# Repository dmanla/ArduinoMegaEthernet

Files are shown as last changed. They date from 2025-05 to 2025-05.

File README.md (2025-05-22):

# Arduino-Mega Compatible Secure Connectivity Development Platform

**WARNING**: This project is under development and has not yet been validated.

This is an open hardware platform designed for the development of secure wired-network applications. It is fully compatible with all Arduino Mega-compatible hardware and software.

This project was inspired by (but not a copy of) the Freetronics EtherMega: https://github.com/freetronics/EtherMega
This project was created as an alternative to the platform offered by Freetronics.

Features:
- CH340 USB->Serial Converter (Functionally similar to FT232, Driver should be installed automatically)
- Jumper Configurable IO: Certain pins (D3, D6, D8, D9, D13) can be connected to the headers or to integrated peripheral pins.
- 5V 2A USB-C Input
- 6V - 32V VIN Input 
- MicroSD Card Slot
- 10/100 Ethernet provided over SPI using the W5500
- SE050 EdgeLock Plug and Trust Secure Element to provide security features for connected applications, accessible using I2C
- ISM330DHCX Inertial Measurement Unit, accessible using I2C
- MCP7940N Real Time Clock, accessible using I2C
- Level Shifted I2C: Provides connection points for 3V3 I2C Devices (Extra Header), and 5V I2C Devices (Standard Mega Headers)

## Top Render
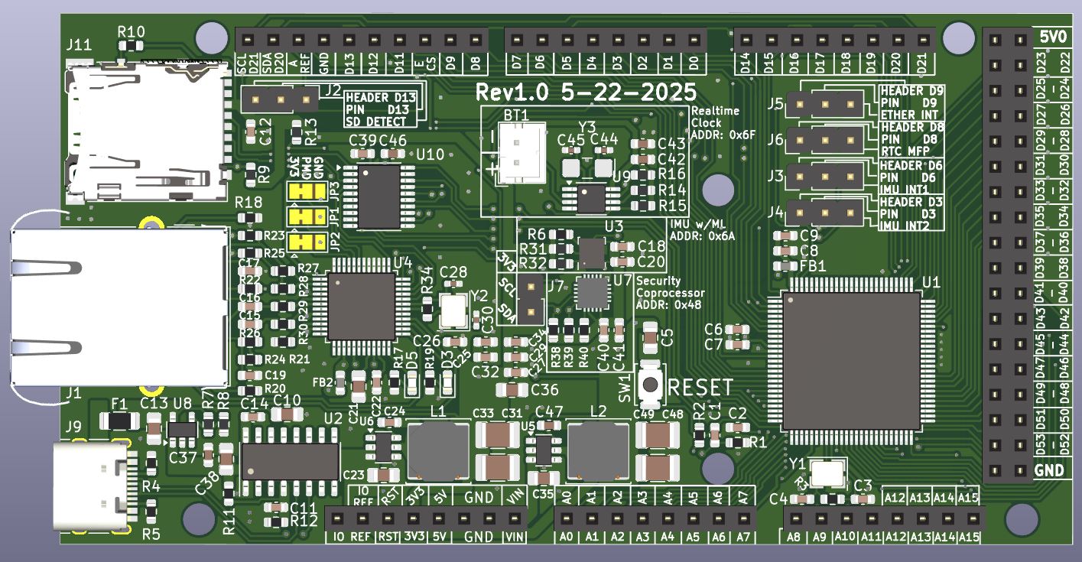
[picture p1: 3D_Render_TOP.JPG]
Render of Top of PCB


## Bottom Render
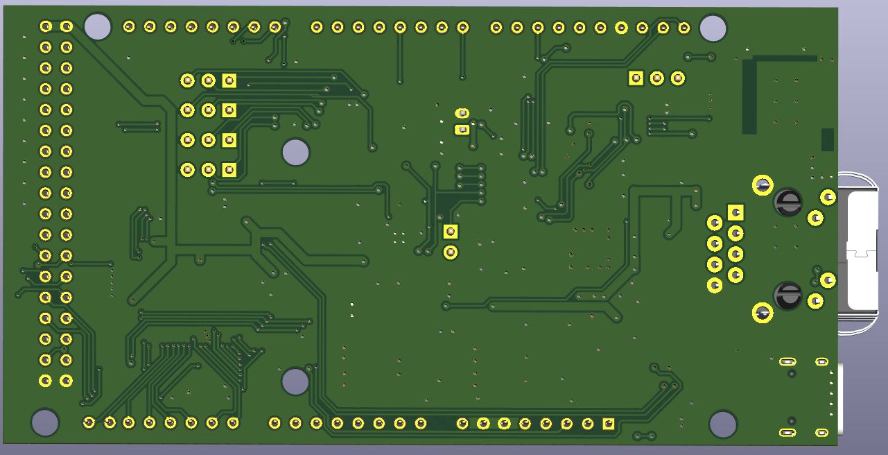
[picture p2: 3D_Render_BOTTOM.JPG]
Render of Bottom of PCB


## Side Render
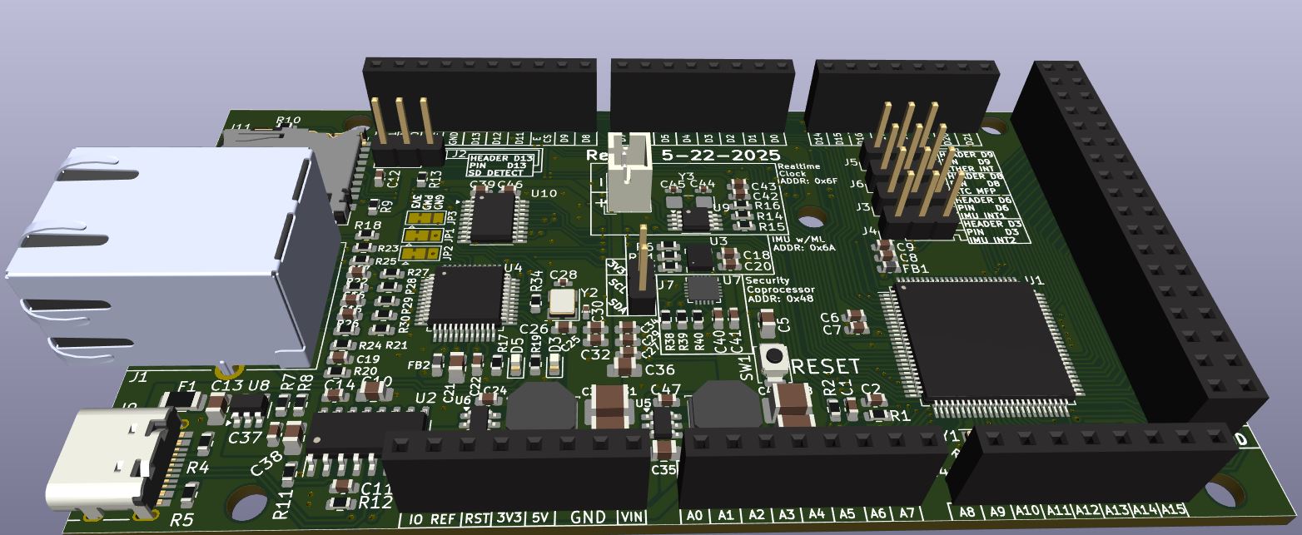
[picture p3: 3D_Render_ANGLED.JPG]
Render of Side of PCB


## Relevant Datasheets

- [CH340N](https://datasheet.lcsc.com/szlcsc/Jiangsu-Qin-Heng-CH340C_C84681.pdf): USB->Serial Bridge
- [AP22805AW5](https://www.diodes.com/assets/Datasheets/AP22804_14.pdf): USB Protection
- [AP63205](https://www.diodes.com/assets/Datasheets/AP63200-AP63201-AP63203-AP63205.pdf): DC-DC Switching Converters
- [W5500](http://wizwiki.net/wiki/lib/exe/fetch.php/products:w5500:w5500_ds_v109e.pdf): SPI->Ethernet Bridge
- [ISM330DHCX](https://www.st.com/resource/en/datasheet/ism330dhcx.pdf): "AI Enabled" Inertial Measurement Unit
- [SE050C2HQ1](https://www.nxp.com/docs/en/data-sheet/SE050-DATASHEET.pdf): Security Coprocessor
- [MCP7940N](http://ww1.microchip.com/downloads/en/DeviceDoc/20005010F.pdf): Real-Time Clock **with** Battery Backup
- [Atmega2560](http://ww1.microchip.com/downloads/en/DeviceDoc/Atmel-2549-8-bit-AVR-Microcontroller-ATmega640-1280-1281-2560-2561_datasheet.pdf): Main Microcontroller

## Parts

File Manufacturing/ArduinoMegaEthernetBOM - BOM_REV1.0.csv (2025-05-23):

 |  |  | Arduino Mega with Ethernet
Item # | Designator | *Qty | Manufacturer | Mfg Part # | Description / Value | Package/Footprint | Type | Your Instructions / Notes | Unit Cost | Per Board Cost
1 | BT1 | 1 | JST Sales America Inc. | B2B-PH-K-S | CONN HEADER VERT 2POS 2MM | JST_PH_B2B-PH-K_1x02_P2.00mm_Vertical | THT | N/A | $0.12 | $0.12
2 | C44, C45 | 2 | Murata Electronics | GRM0335C1H120JA01D | CAP CER 12PF 50V C0G/NP0 0603 | 0402 (1005 Metric) | SMD | N/A | $0.10 | $0.20
3 | C2, C3, C4 | 2 | Walsin Technology | 0603N220J500CT | CAP CER 22PF 50V C0G/NP0 0603 | C_0603_1608Metric | SMD | N/A | $0.10 | $0.20
4 | C5, C13, C23, C35, C36, C38 | 6 | Murata Electronics | GRM21BR61H106KE43L | CAP CER 10UF 50V X5R 0805 | C_0805_2012Metric | SMD | N/A | $0.17 | $0.99
5 | C6, C20, C34, C39, C41, C43, C46 | 7 | Samsung Electro-Mechanics | CL10B105KP8NNNC | CAP CER 1UF 10V X7R 0603 | C_0603_1608Metric | SMD | N/A | $0.08 | $0.56
6 | C1, C7-C9, C11, C12, C14, C18, C24-C27, C29, C32, C37, C40, C42, C47 | 18 | Samsung Electro-Mechanics | CL10B104KA8NNNC | CAP CER 0.1UF 25V X7R 0603 | C_0603_1608Metric | SMD | N/A | $0.08 | $1.44
7 | C10, C21 | 2 | Murata Electronics | GRM21BR71C475KE51K | CAP CER 4.7UF 16V X7R 0805 | C_0805_2012Metric | SMD | N/A | $0.12 | $0.24
8 | C15, C16 | 2 | Samsung Electro-Mechanics | CL10B682JB8NNNC | CAP CER 6800PF 50V X7R 0603 | C_0603_1608Metric | SMD | N/A | $0.10 | $0.20
9 | C17 | 1 | Samsung Electro-Mechanics | CL10B223KB8WPNC | CAP CER 0.022UF 50V X7R 0603 | C_0603_1608Metric | SMD | N/A | $0.10 | $0.10
10 | C19, C22 | 2 | Samsung Electro-Mechanics | CL10B103KB8NNNC | CAP CER 10000PF 50V X7R 0603 | C_0603_1608Metric | SMD | N/A | $0.08 | $0.16
11 | C28, C30 | 2 | Murata Electronics | GJM1555C1H180GB01D | CAP CER 18PF 50V C0G/NP0 0402 | C_0603_1608Metric | SMD | N/A | $0.14 | $0.28
12 | C31, C33, C48, C49 | 4 | Samsung Electro-Mechanics | CL31B226KPHNNNE | CAP CER 22UF 10V X7R 1206 | C_0805_2012Metric_Pad1.18x1.45mm | SMD | N/A | $0.39 | $1.56
13 | D3 | 1 | Lite-On Inc. | LTST-C190KFKT | LED ORANGE CLEAR CHIP SMD | LED_0603_1608Metric | SMD | N/A | $0.13 | $0.13
14 | D5 | 1 | Lite-On Inc. | LTST-C190GKT | LED GREEN CLEAR CHIP SMD | LED_0603_1608Metric | SMD | N/A | $0.14 | $0.14
15 | F1 | 1 | YAGEO | SMD1206B200TF | PTC RESET FUSE 6V 2A 1206 | Fuse_1206_3216Metric | SMD | N/A | $0.13 | $0.13
16 | FB1, FB2 | 2 | Murata Electronics | BLM18KG121TN1D | FERRITE BEAD 120 OHM 0603 1LN | L_0603_1608Metric | SMD | N/A | $0.10 | $0.20
17 | J1 | 1 | Amphenol ICC | RJMG1BD3B8K1ANR | RJ45_Amphenol_RJMG1BD3B8K1ANR | RJ45_Amphenol_RJMG1BD3B8K1ANR | THT | N/A | $4.22 | $4.22
18 | J2, J3, J4, J5, J6 | 5 | Würth Elektronik | 61300311121 | CONN HEADER VERT 3POS 2.54MM | PinHeader_1x03_P2.54mm_Vertical | SMD | N/A | $0.12 | $0.60
19 | J7 | 1 | Würth Elektronik | 61300211121 | CONN HEADER VERT 2POS 2.54MM | PinHeader_1x02_P2.54mm_Vertical | SMD | N/A | $0.12 | $0.12
20 | J9 | 1 | Same Sky | UJ20-C-H-G-SMT-P16-TR | USB JACK, TYPE C, 2.0, HORIZONTAL | USB_C_Receptacle_HRO_TYPE-C-31-M-12 | SMD | N/A | $0.57 | $0.57
21 | J11 | 1 | Hirose Electric Co Ltd | DM3AT-SF-PEJM5 | CONN MICRO SD CARD R/A SMD | microSD_HC_Hirose_DM3AT-SF-PEJM5 | SMD | N/A | $2.66 | $2.66
22 | L1, L2 | 2 | Taiyo Yuden | NRS6028T4R7MMGKV | FIXED IND 4.7UH 3A 40.3 MOHM SMD | 0.236" L x 0.236" W (6.00mm x 6.00mm) | SMD | N/A | $0.29 | $0.58
23 | R1, R2, R6, R9, R10, R13 | 6 | YAGEO | WR06X1002FTL | RES 10K OHM 1% 1/10W 0603 | R_0603_1608Metric | SMD | N/A | $0.10 | $0.60
24 | R3, R34 | 2 | YAGEO | AC0603FR-101ML | RES 1M OHM 1% 1/10W 0603 | R_0603_1608Metric | SMD | N/A | $0.10 | $0.20
25 | R4, R5, R7 | 3 | YAGEO | RC0603FR-075K1L | RES 5.1K OHM 1% 1/10W 0603 | R_0603_1608Metric | SMD | N/A | $0.10 | $0.30
26 | R8 | 1 |  |  | DNP | R_0603_1608Metric | SMD | DO NOT PLACE |  | $0.00
27 | R11 | 1 | YAGEO | RC0603FR-0722K1L | RES 22.1K OHM 1% 1/10W 0603 | R_0603_1608Metric | SMD | N/A | $0.10 | $0.10
28 | R12 | 1 | YAGEO | RC0603FR-0747K5L | RES 47.5K OHM 1% 1/10W 0603 | R_0603_1608Metric | SMD | N/A | $0.10 | $0.10
29 | R14-R16, R31, R32, R38-R40 | 8 | YAGEO | RC0603FR-134K7L | RES 4.7K OHM 1% 1/10W 0603 | R_0603_1608Metric | SMD | N/A | $0.10 | $0.80
30 | R17-R20 | 4 | YAGEO | RC0603FR-07330RL | RES 330 OHM 1% 1/10W 0603 | R_0603_1608Metric | SMD | N/A | $0.10 | $0.40
31 | R21 | 1 | YAGEO | RC0603FR-0712K4L | RES 12.4K OHM 1% 1/10W 0603 | R_0603_1608Metric | SMD | N/A | $0.10 | $0.10
32 | R22 | 1 | YAGEO | AC0603FR-0710RL | RES SMD 10 OHM 1% 1/10W 0603 | R_0603_1608Metric | SMD | N/A | $0.10 | $0.10
33 | R23, R25 | 2 | YAGEO | RC0603FR-0749R9L | RC0603FR-0749R9L | R_0603_1608Metric | SMD | N/A | $0.10 | $0.20
34 | R24, R26 | 2 | YAGEO | RC0603FR-0782RL | RES 82 OHM 1% 1/10W 0603 | R_0603_1608Metric | SMD | N/A | $0.10 | $0.20
35 | R27-R30 | 4 | YAGEO | RT0603DRE0733RL | RES SMD 33 OHM 0.5% 1/10W 0603 | R_0603_1608Metric | SMD | N/A | $0.10 | $0.40
36 | SW1 | 1 | Alps Alpine | SKRKAHE020 | SWITCH TACTILE SPST-NO 0.05A 12V | SW_SPST_PTS645 | SMD | N/A | $0.41 | $0.41
37 | U1 | 1 | Microchip Technology | ATMEGA2560-16AU | IC MCU 8BIT 256KB FLASH 100TQFP | TQFP-100_14x14mm_P0.5mm | SMD | N/A | $17.30 | $17.30
38 | U2 | 1 | WCH(Jiangsu Qin Heng) | CH340C | 2Mbps transceiver USB 2.0 SOP-16 USB | SOIC-16_3.9x9.9mm_P1.27mm | SMD | N/A | $0.52 | $0.52
39 | U3 | 1 | STMicroelectronics | ISM330DHCXTR | INEMO INERTIAL MODULE: ALWAYS-ON | LGA-14_3x2.5mm_P0.5mm_LayoutBorder3x4y | SMD | N/A | $6.56 | $6.56
40 | U4 | 1 | WIZnet | W5500 | IC CTLR 3-1 ETH TCP/IP 48LQFP | LQFP-48_7x7mm_P0.5mm | SMD | N/A | $3.60 | $3.60
41 | U5 | 1 | Diodes Incorporated | AP63205QWU-7 | IC REG BUCK 5V 2A TSOT23-6 | TSOT-23-6 | SMD | N/A | $0.96 | $0.96
42 | U6 | 1 | Diodes Incorporated | AP63203WU-7 | IC REG BUCK 3.3V 2A TSOT23-6 | TSOT-23-6 | SMD | N/A | $0.71 | $0.71
43 | U7 | 1 | NXP USA Inc. | SE050C2HQ1/Z01SDZ | IC IOT SECURE ELEMENT 20-HX2QFN | QFN-20-1EP_3x3mm_P0.4mm_EP1.65x1.65mm | SMD | N/A | $5.19 | $5.19
44 | U8 | 1 | Diodes Incorporated | AP22804AW5-7 | IC PWR SWITCH P-CHAN 1:1 SOT25 | SOT-23-5 | SMD | N/A | $0.35 | $0.35
45 | U9 | 1 | Microchip Technology | MCP7940N-E/MS | IC RTC CLK/CALENDAR I2C 8MSOP | MSOP-8_3x3mm_P0.65mm | SMD | N/A | $0.97 | $0.97
46 | U10 | 1 | Texas Instruments | TXS0108EPWR | IC TRANSLATOR BIDIR 20TSSOP | TSSOP-20_4.4x6.5mm_P0.65mm | SMD | N/A | $1.25 | $1.25
47 | Y1 | 1 | Jauch Quartz | Q 16,0-JXS32-12-10/15-T1-WA-LF | CRYSTAL 16.0000MHZ 12PF SMD | Crystal_SMD_3225-4Pin_3.2x2.5mm | SMD | N/A | $0.64 | $0.64
48 | Y2 | 1 | Raltron Electronics | RH100-25.000-10-F-2030-EXT-TR | CRYSTAL 25.0000MHZ 10PF SMD | Crystal_SMD_3225-4Pin_3.2x2.5mm | SMD | N/A | $0.23 | $0.23
49 | Y3 | 1 | YIC | 32.768K7PI/3215E | CRYSTAL 32.7680KHZ 7PF SMD | 0.126" L x 0.059" W (3.20mm x 1.50mm) | SMD | N/A | $0.28 | $0.28
 |  |  |  |  |  |  |  | Total Cost Per Board: |  | $57.88

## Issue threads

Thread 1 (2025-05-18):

SD Card Interfacing lacks recommended pull-up resistors

dmanla, 2025-05-18:
The current SD Card Interface needs pull-up resistors added to the SPI lines, as is recommend for SD Card SPI Interfacing.

dmanla, 2025-05-18:
A pull-up resistor was added to the SD CS and MISO pin. Pending further review.

dmanla, 2025-05-22:
This is fixed.

Closed 2025-05-22.

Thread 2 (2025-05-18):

There is no bill-of-materials.

dmanla, 2025-05-18:
A bill of materials needs to be generated to enable manufacturing of prototype boards.

dmanla, 2025-05-22:
This is in progress.

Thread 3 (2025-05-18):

I2C Routing to IMU does not exist.

dmanla, 2025-05-18:
The IMU I2C data lines are not connected to anything.

It may make sense to utilize the SPI interface rather than I2C, given that the level shifting for SPI already exists. The bidirectional nature of SDA will require new level shifting hardware.

dmanla, 2025-05-18:
Should be good now. IMU was moved closed to the Security Coprocessor due to its shared usage of the I2C Lines. Security Coprocessor was incorrectly connected to 5V. This was fixed also.

Closed 2025-05-18.

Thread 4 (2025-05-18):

Inaccessible IO

dmanla, 2025-05-18:
Certain IO, such as the IMU interrupts, are not accessible to the central microcontroller.

All IO on the board should be available. That availability should be provided through the use of jumpers configured to prevent the connection of the 3.3V IO with the externally facing 5V headers.

dmanla, 2025-05-19:
IO have been connected to headers which can be connected to MCU pins using the added headers.

Closed 2025-05-19.

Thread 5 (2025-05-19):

Missing ICSP Header

dmanla, 2025-05-19:
A header is not made available to enable easy flashing of the bootloader.

It may still be possible to flash the MCU using the GPIO headers.

A dedicated header should be added for ICSP.

dmanla, 2025-05-22:
An ICSP header will not be added due to a lack of space. The headers already on the board expose the necessary pins in a less convenient manner.

Closed 2025-05-22.

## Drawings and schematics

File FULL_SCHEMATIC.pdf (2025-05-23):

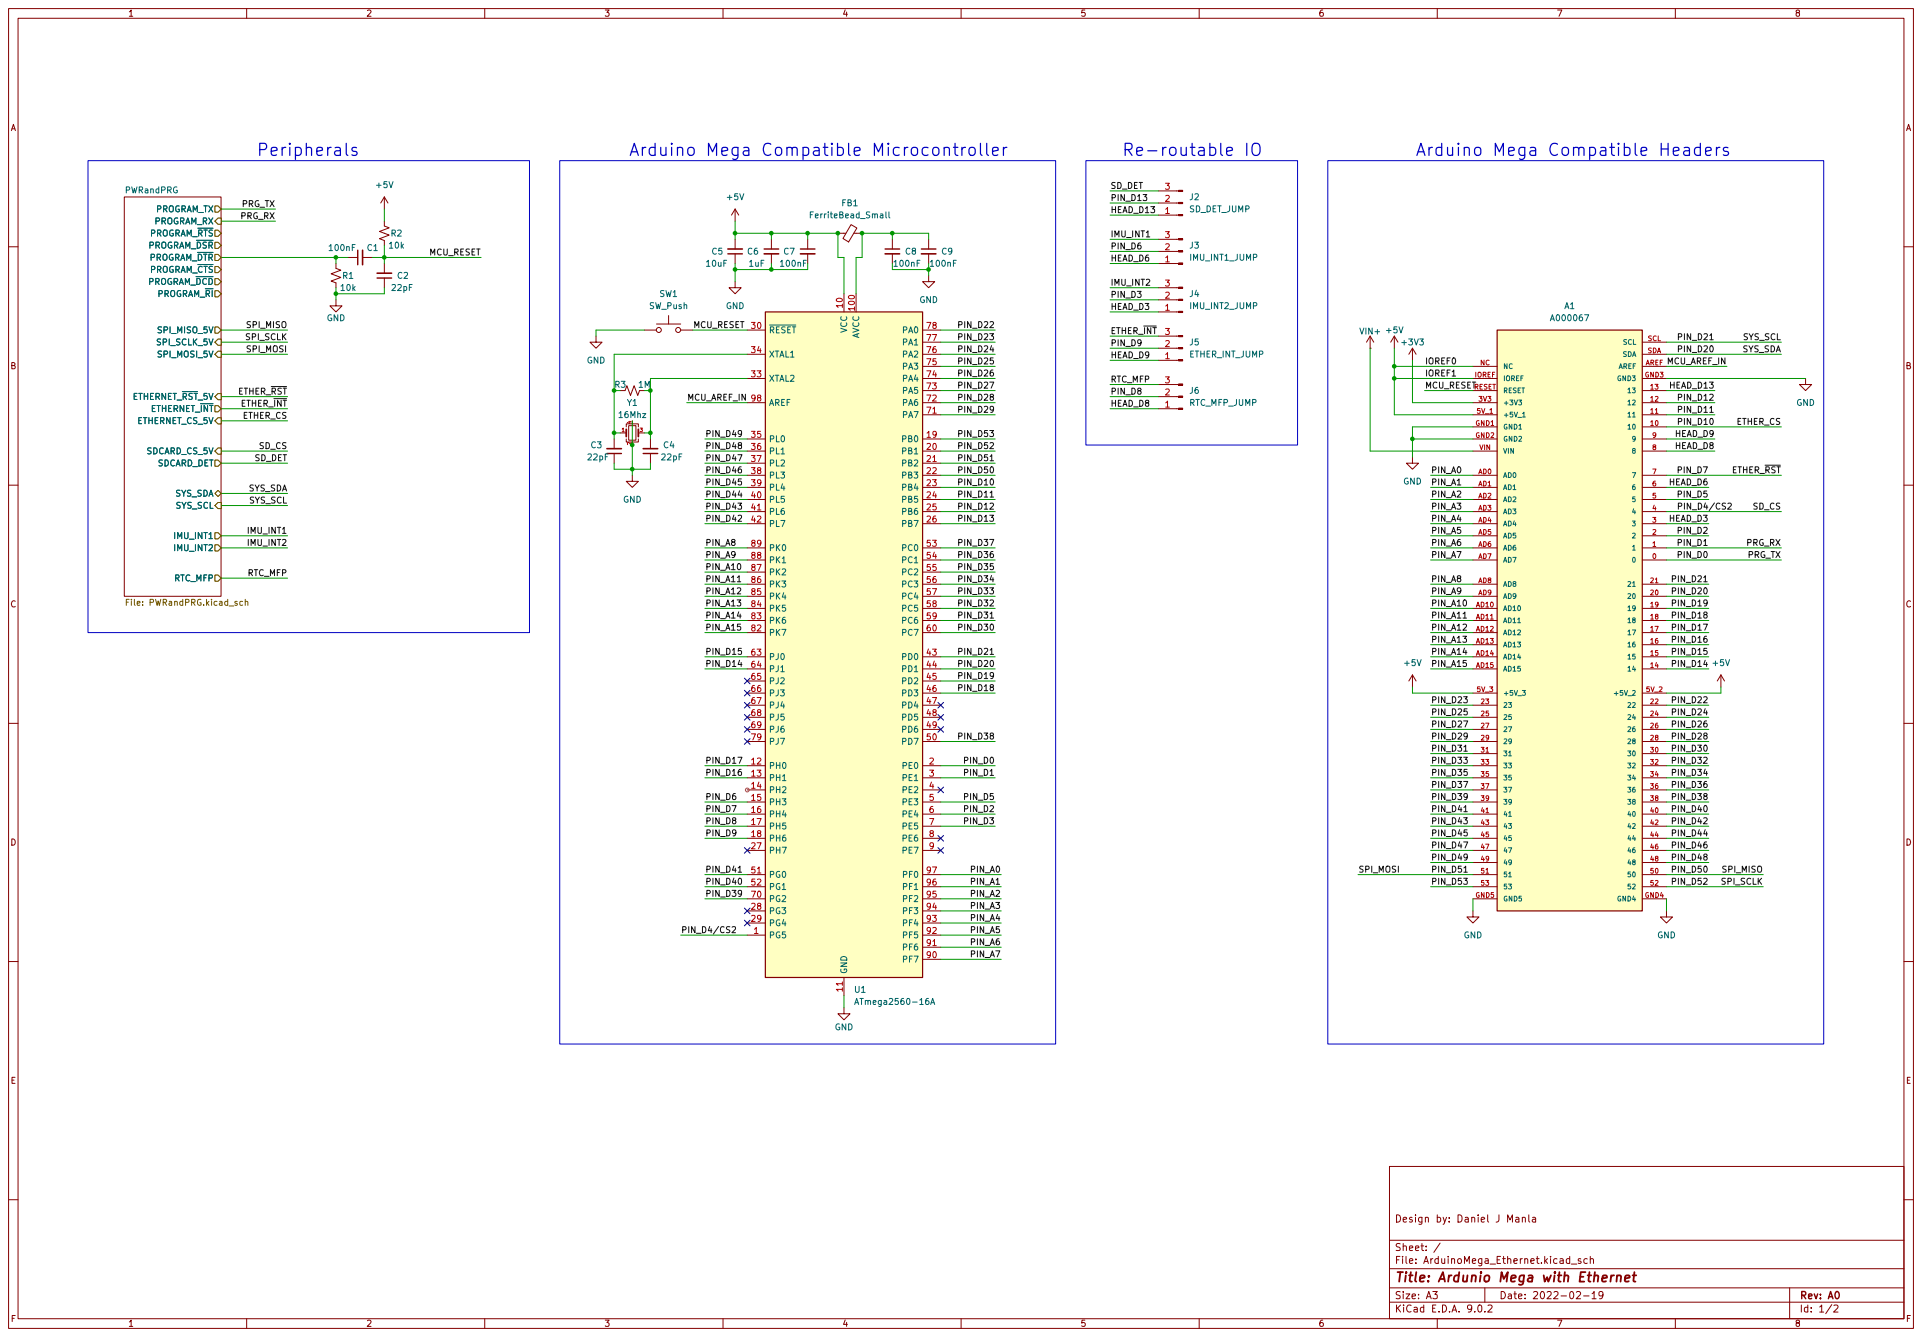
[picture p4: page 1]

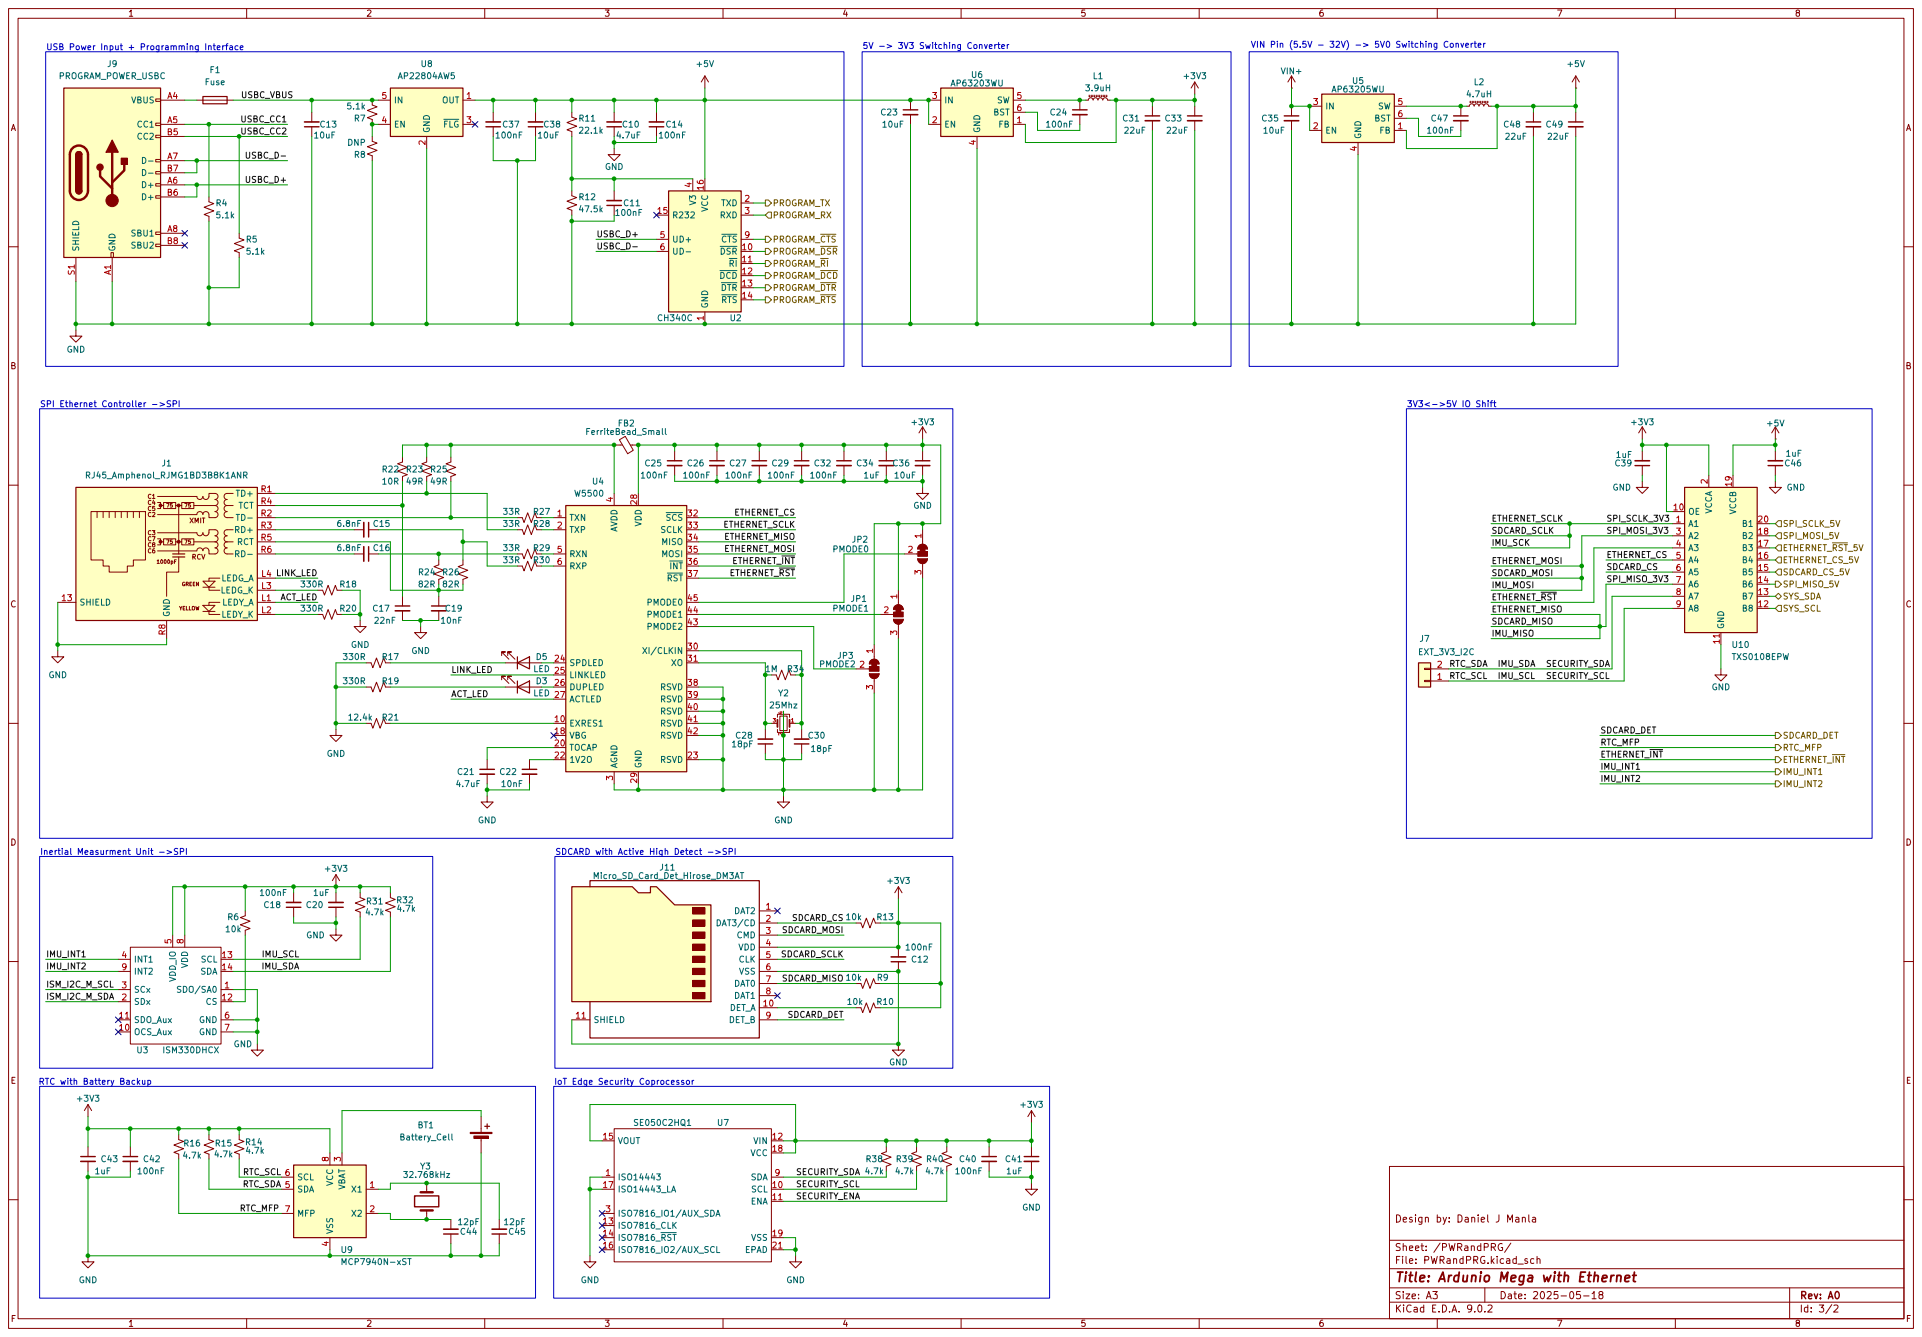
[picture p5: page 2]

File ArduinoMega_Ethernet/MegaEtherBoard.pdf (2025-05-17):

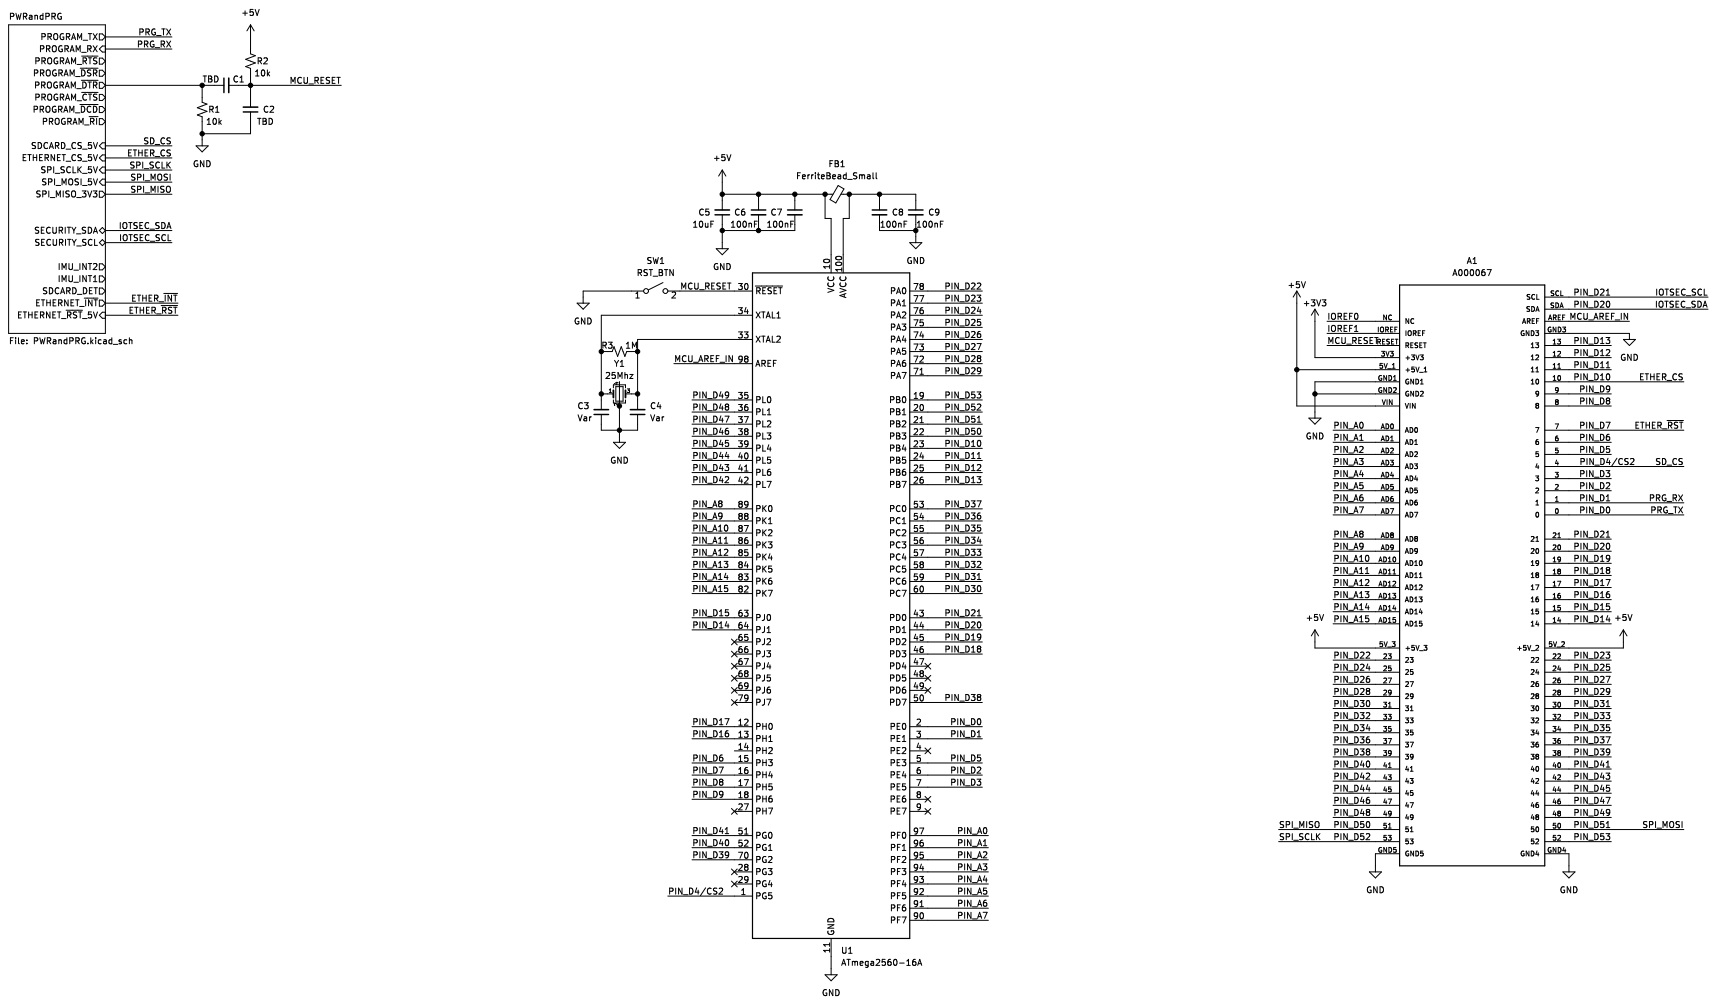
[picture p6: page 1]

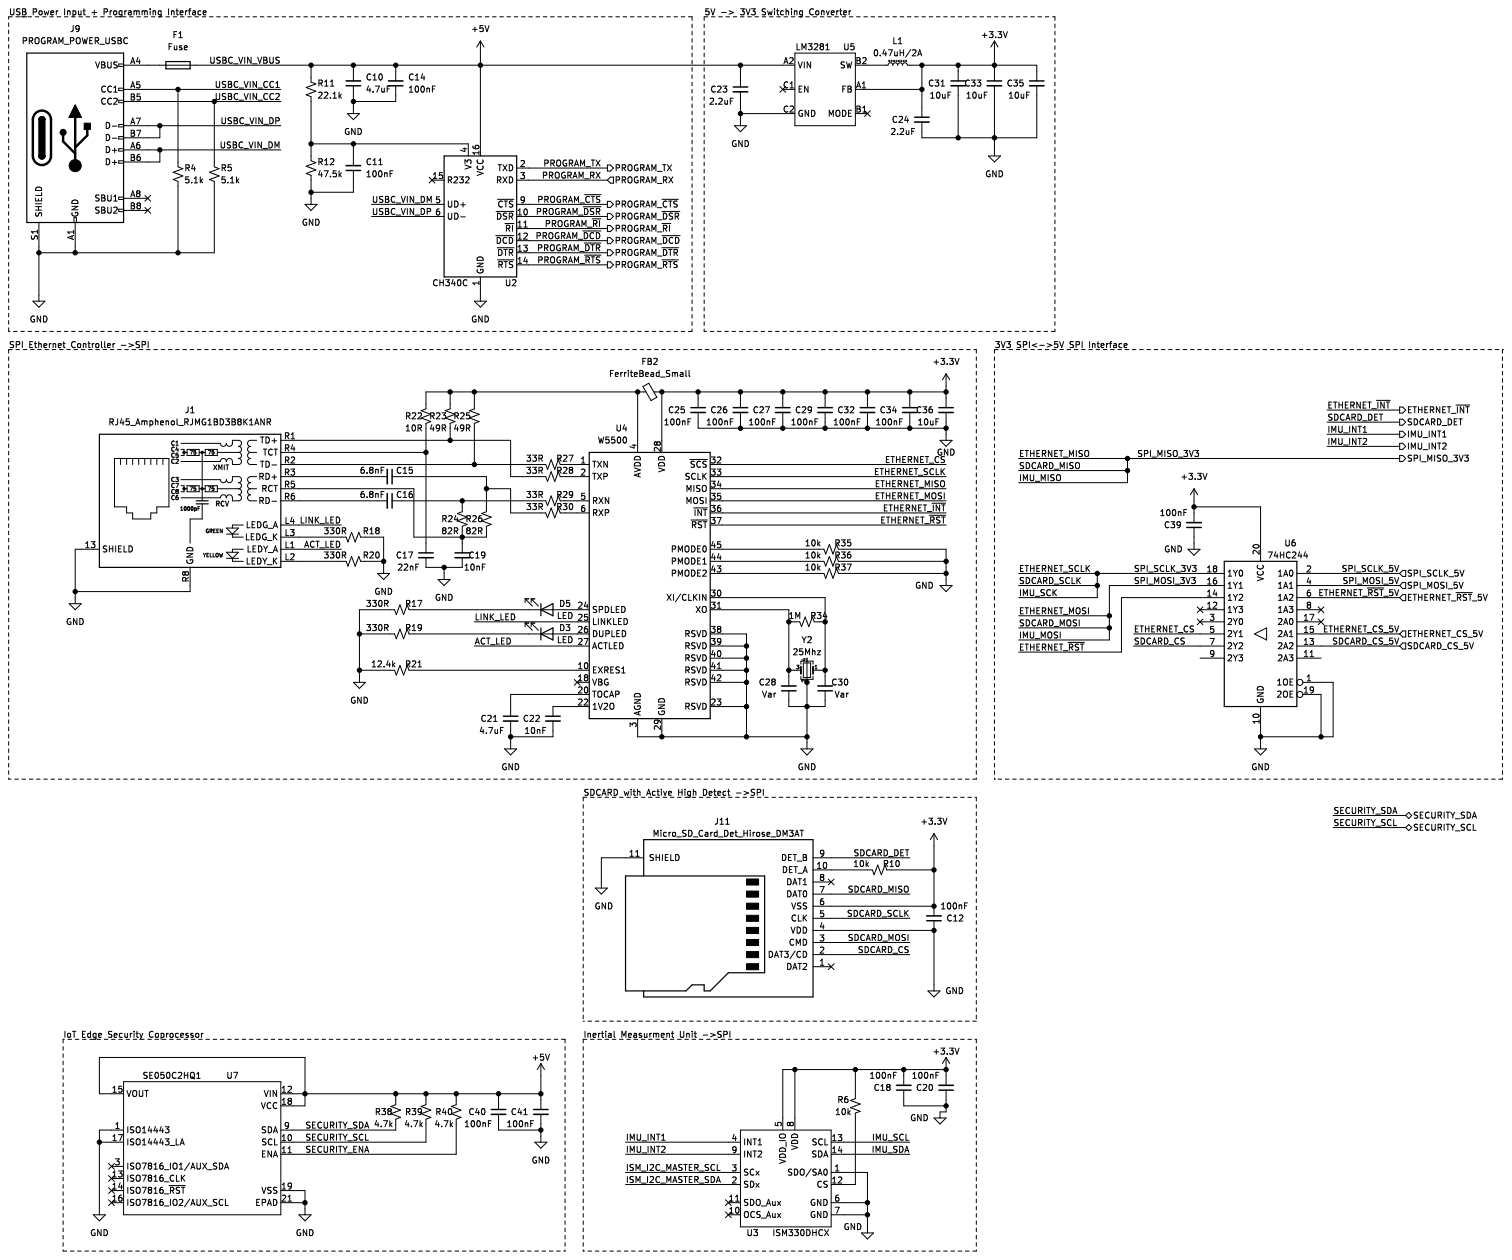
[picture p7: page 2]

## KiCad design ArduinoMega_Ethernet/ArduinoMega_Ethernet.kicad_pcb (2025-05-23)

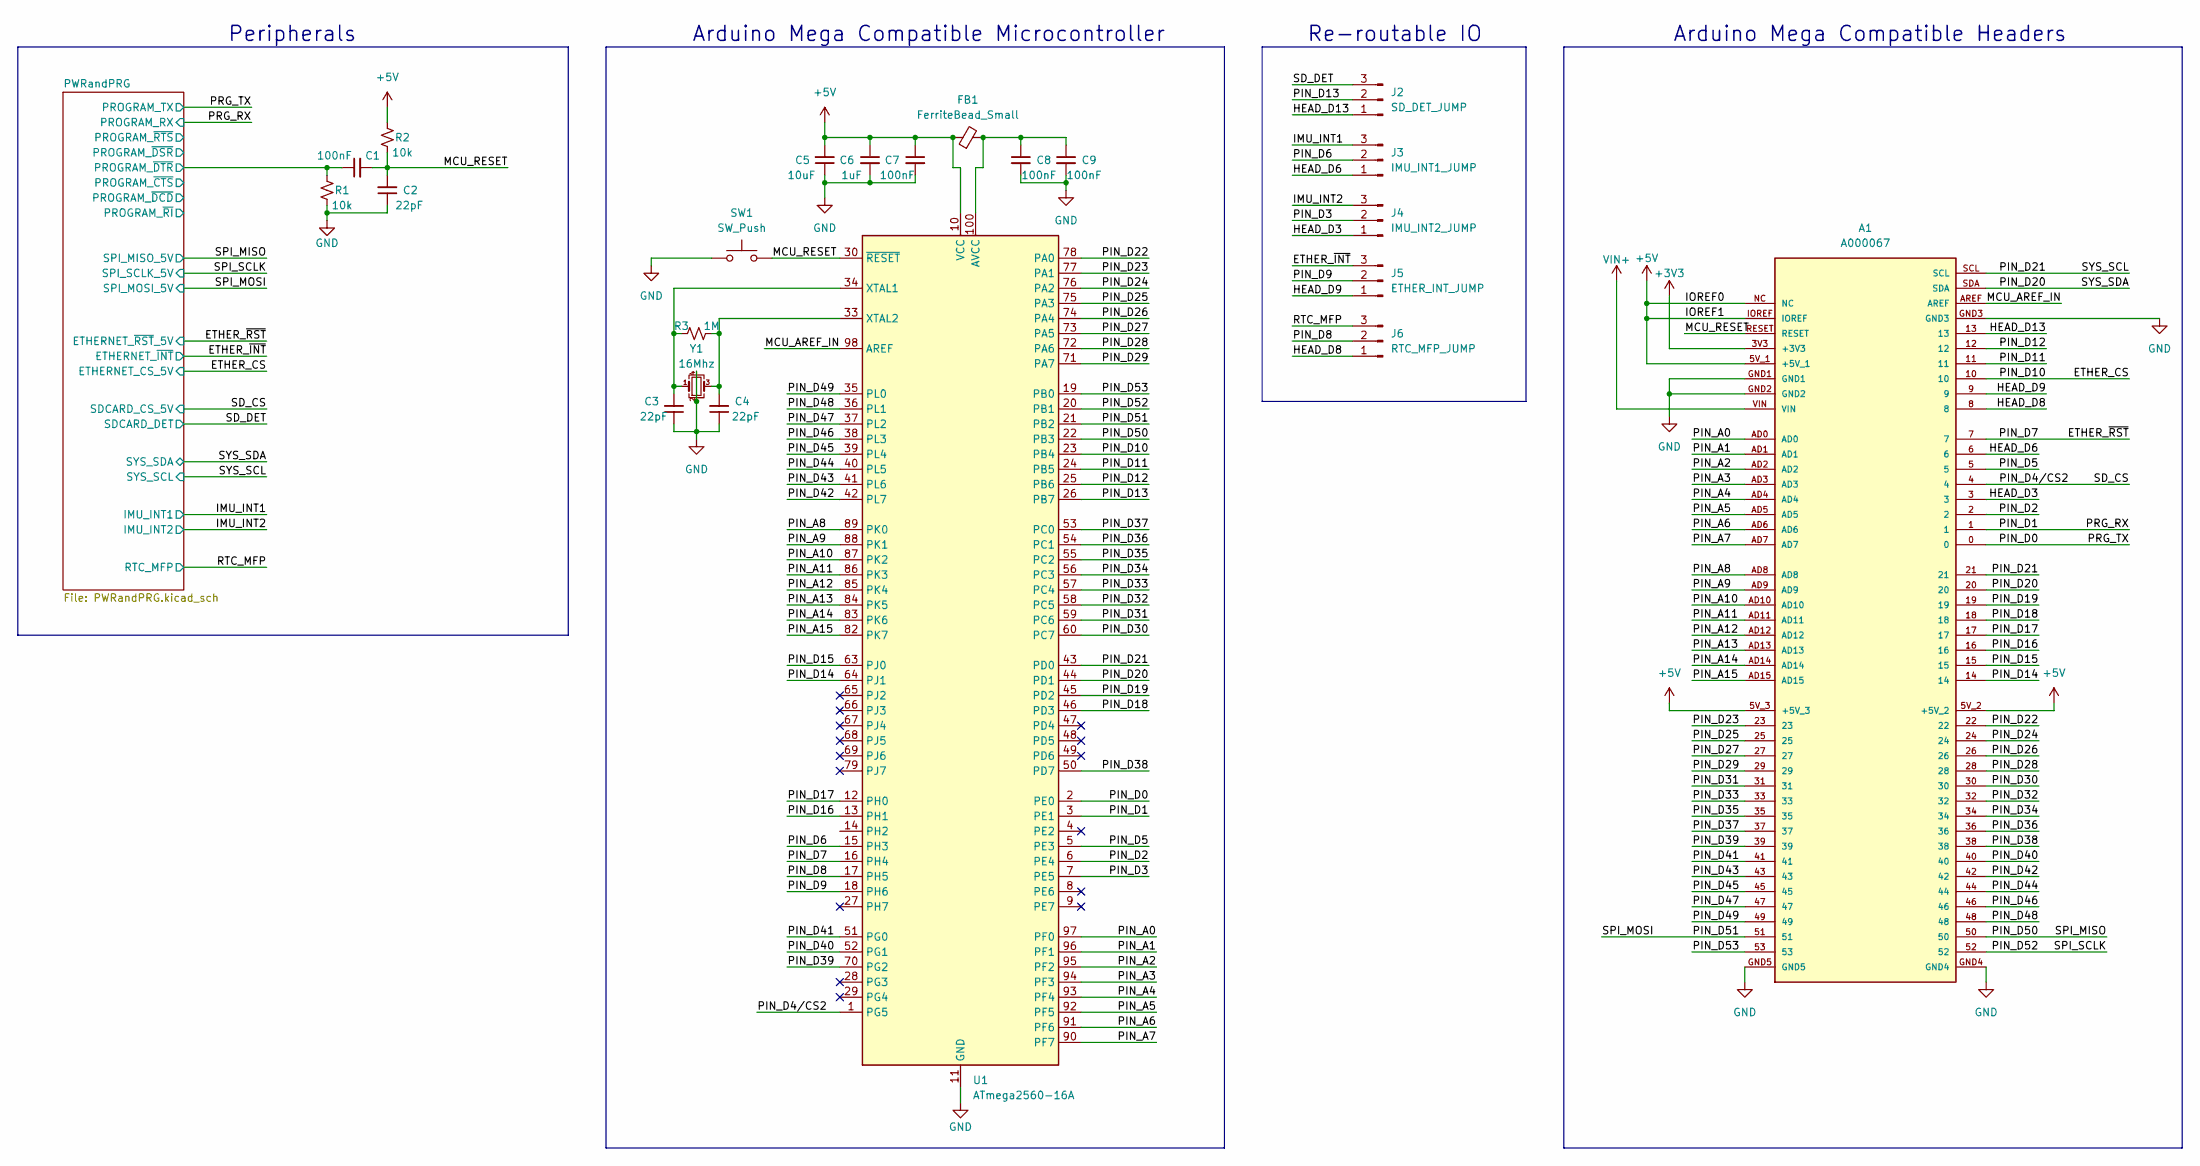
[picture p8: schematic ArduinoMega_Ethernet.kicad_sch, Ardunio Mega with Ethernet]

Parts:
A1: A000067; ARDUINO_A000067
C1, C7, C8, C9: 100nF; C_0603_1608Metric
C2, C3, C4: 22pF; C_0603_1608Metric
C5: 10uF; C_0805_2012Metric_Pad1.18x1.45mm_HandSolder
C6: 1uF; C_0603_1608Metric
FB1: FerriteBead_Small; L_0603_1608Metric
J2: SD_DET_JUMP; PinHeader_1x03_P2.54mm_Vertical
J3: IMU_INT1_JUMP; PinHeader_1x03_P2.54mm_Vertical
J4: IMU_INT2_JUMP; PinHeader_1x03_P2.54mm_Vertical
J5: ETHER_INT_JUMP; PinHeader_1x03_P2.54mm_Vertical
J6: RTC_MFP_JUMP; PinHeader_1x03_P2.54mm_Vertical
R1, R2: 10k; R_0603_1608Metric
R3: 1M; R_0603_1608Metric
SW1: SW_Push; SW_Push_SPST_NO_Alps_SKRK
U1: ATmega2560-16A; TQFP-100_14x14mm_P0.5mm
Y1: 16Mhz; Crystal_SMD_3225-4Pin_3.2x2.5mm

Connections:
+3V3: A1.3V3 (+3V3); also elsewhere on the board
+5V: A1.5V_1 (+5V_1), A1.5V_2 (+5V_2), A1.5V_3 (+5V_3), A1.IOREF, A1.NC, C5.2, C6.1, C7.1, FB1.1, R2.1, U1.10 (VCC), U1.31 (VCC), U1.61 (VCC), U1.80 (VCC); also elsewhere on the board
/ETHER_CS: A1.10, U1.23 (PB4); also elsewhere on the board
/ETHER_~INT: J5.3; also elsewhere on the board
/ETHER_~RST: A1.7, U1.16 (PH4); also elsewhere on the board
/HEAD_D3: A1.3, J4.1
/HEAD_D6: A1.6, J3.1
/HEAD_D8: A1.8, J6.1
/HEAD_D9: A1.9, J5.1
/HEAD_D13: A1.13, J2.1
/IMU_INT1: J3.3; also elsewhere on the board
/IMU_INT2: J4.3; also elsewhere on the board
/MCU_AREF_IN: A1.AREF, U1.98 (AREF)
/MCU_RESET: A1.RESET, C1.2, C2.2, R2.2, SW1.2, U1.30 (~RESET)
/PIN_A0: A1.AD0, U1.97 (PF0)
/PIN_A1: A1.AD1, U1.96 (PF1)
/PIN_A2: A1.AD2, U1.95 (PF2)
/PIN_A3: A1.AD3, U1.94 (PF3)
/PIN_A4: A1.AD4, U1.93 (PF4)
/PIN_A5: A1.AD5, U1.92 (PF5)
/PIN_A6: A1.AD6, U1.91 (PF6)
/PIN_A7: A1.AD7, U1.90 (PF7)
/PIN_A8: A1.AD8, U1.89 (PK0)
/PIN_A9: A1.AD9, U1.88 (PK1)
/PIN_A10: A1.AD10, U1.87 (PK2)
/PIN_A11: A1.AD11, U1.86 (PK3)
/PIN_A12: A1.AD12, U1.85 (PK4)
/PIN_A13: A1.AD13, U1.84 (PK5)
/PIN_A14: A1.AD14, U1.83 (PK6)
/PIN_A15: A1.AD15, U1.82 (PK7)
/PIN_D0: A1.0, U1.2 (PE0); also elsewhere on the board
/PIN_D1: A1.1, U1.3 (PE1); also elsewhere on the board
/PIN_D2: A1.2, U1.6 (PE4)
/PIN_D3: J4.2, U1.7 (PE5)
/PIN_D4/CS2: A1.4, U1.1 (PG5); also elsewhere on the board
/PIN_D5: A1.5, U1.5 (PE3)
/PIN_D6: J3.2, U1.15 (PH3)
/PIN_D8: J6.2, U1.17 (PH5)
/PIN_D9: J5.2, U1.18 (PH6)
/PIN_D11: A1.11, U1.24 (PB5)
/PIN_D12: A1.12, U1.25 (PB6)
/PIN_D13: J2.2, U1.26 (PB7)
/PIN_D14: A1.14, U1.64 (PJ1)
/PIN_D15: A1.15, U1.63 (PJ0)
/PIN_D16: A1.16, U1.13 (PH1)
/PIN_D17: A1.17, U1.12 (PH0)
/PIN_D18: A1.18, U1.46 (PD3)
/PIN_D19: A1.19, U1.45 (PD2)
/PIN_D20: A1.20, A1.SDA, U1.44 (PD1); also elsewhere on the board
/PIN_D21: A1.21, A1.SCL, U1.43 (PD0); also elsewhere on the board
/PIN_D22: A1.22, U1.78 (PA0)
/PIN_D23: A1.23, U1.77 (PA1)
/PIN_D24: A1.24, U1.76 (PA2)
/PIN_D25: A1.25, U1.75 (PA3)
/PIN_D26: A1.26, U1.74 (PA4)
/PIN_D27: A1.27, U1.73 (PA5)
/PIN_D28: A1.28, U1.72 (PA6)
/PIN_D29: A1.29, U1.71 (PA7)
/PIN_D30: A1.30, U1.60 (PC7)
/PIN_D31: A1.31, U1.59 (PC6)
/PIN_D32: A1.32, U1.58 (PC5)
/PIN_D33: A1.33, U1.57 (PC4)
/PIN_D34: A1.34, U1.56 (PC3)
/PIN_D35: A1.35, U1.55 (PC2)
/PIN_D36: A1.36, U1.54 (PC1)
/PIN_D37: A1.37, U1.53 (PC0)
/PIN_D38: A1.38, U1.50 (PD7)
/PIN_D39: A1.39, U1.70 (PG2)
/PIN_D40: A1.40, U1.52 (PG1)
/PIN_D41: A1.41, U1.51 (PG0)
/PIN_D42: A1.42, U1.42 (PL7)
/PIN_D43: A1.43, U1.41 (PL6)
/PIN_D44: A1.44, U1.40 (PL5)
/PIN_D45: A1.45, U1.39 (PL4)
/PIN_D46: A1.46, U1.38 (PL3)
/PIN_D47: A1.47, U1.37 (PL2)
/PIN_D48: A1.48, U1.36 (PL1)
/PIN_D49: A1.49, U1.35 (PL0)
/PIN_D50: A1.50, U1.22 (PB3); also elsewhere on the board
/PIN_D51: A1.51, U1.21 (PB2); also elsewhere on the board
/PIN_D52: A1.52, U1.20 (PB1); also elsewhere on the board
/PIN_D53: A1.53, U1.19 (PB0)
/PWRandPRG/PROGRAM_~DTR: C1.1, R1.1; also elsewhere on the board
/RTC_MFP: J6.3; also elsewhere on the board
/SD_DET: J2.3; also elsewhere on the board
GND: A1.GND1, A1.GND2, A1.GND3, A1.GND4, A1.GND5, C2.1, C3.1, C4.1, C5.1, C6.2, C7.2, C8.2, C9.2, R1.2, SW1.1, U1.11 (GND), U1.32 (GND), U1.62 (GND), U1.81 (GND), U1.99 (GND), Y1.2, Y1.4; also elsewhere on the board
unnamed: C8.1, C9.1, FB1.2, U1.100 (AVCC)
unnamed: C3.2, R3.1, U1.34 (XTAL1), Y1.1
unnamed: C4.2, R3.2, U1.33 (XTAL2), Y1.3
VIN+: A1.VIN; also elsewhere on the board

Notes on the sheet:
Peripherals
Arduino Mega Compatible Headers
Re-routable IO
Arduino Mega Compatible Microcontroller

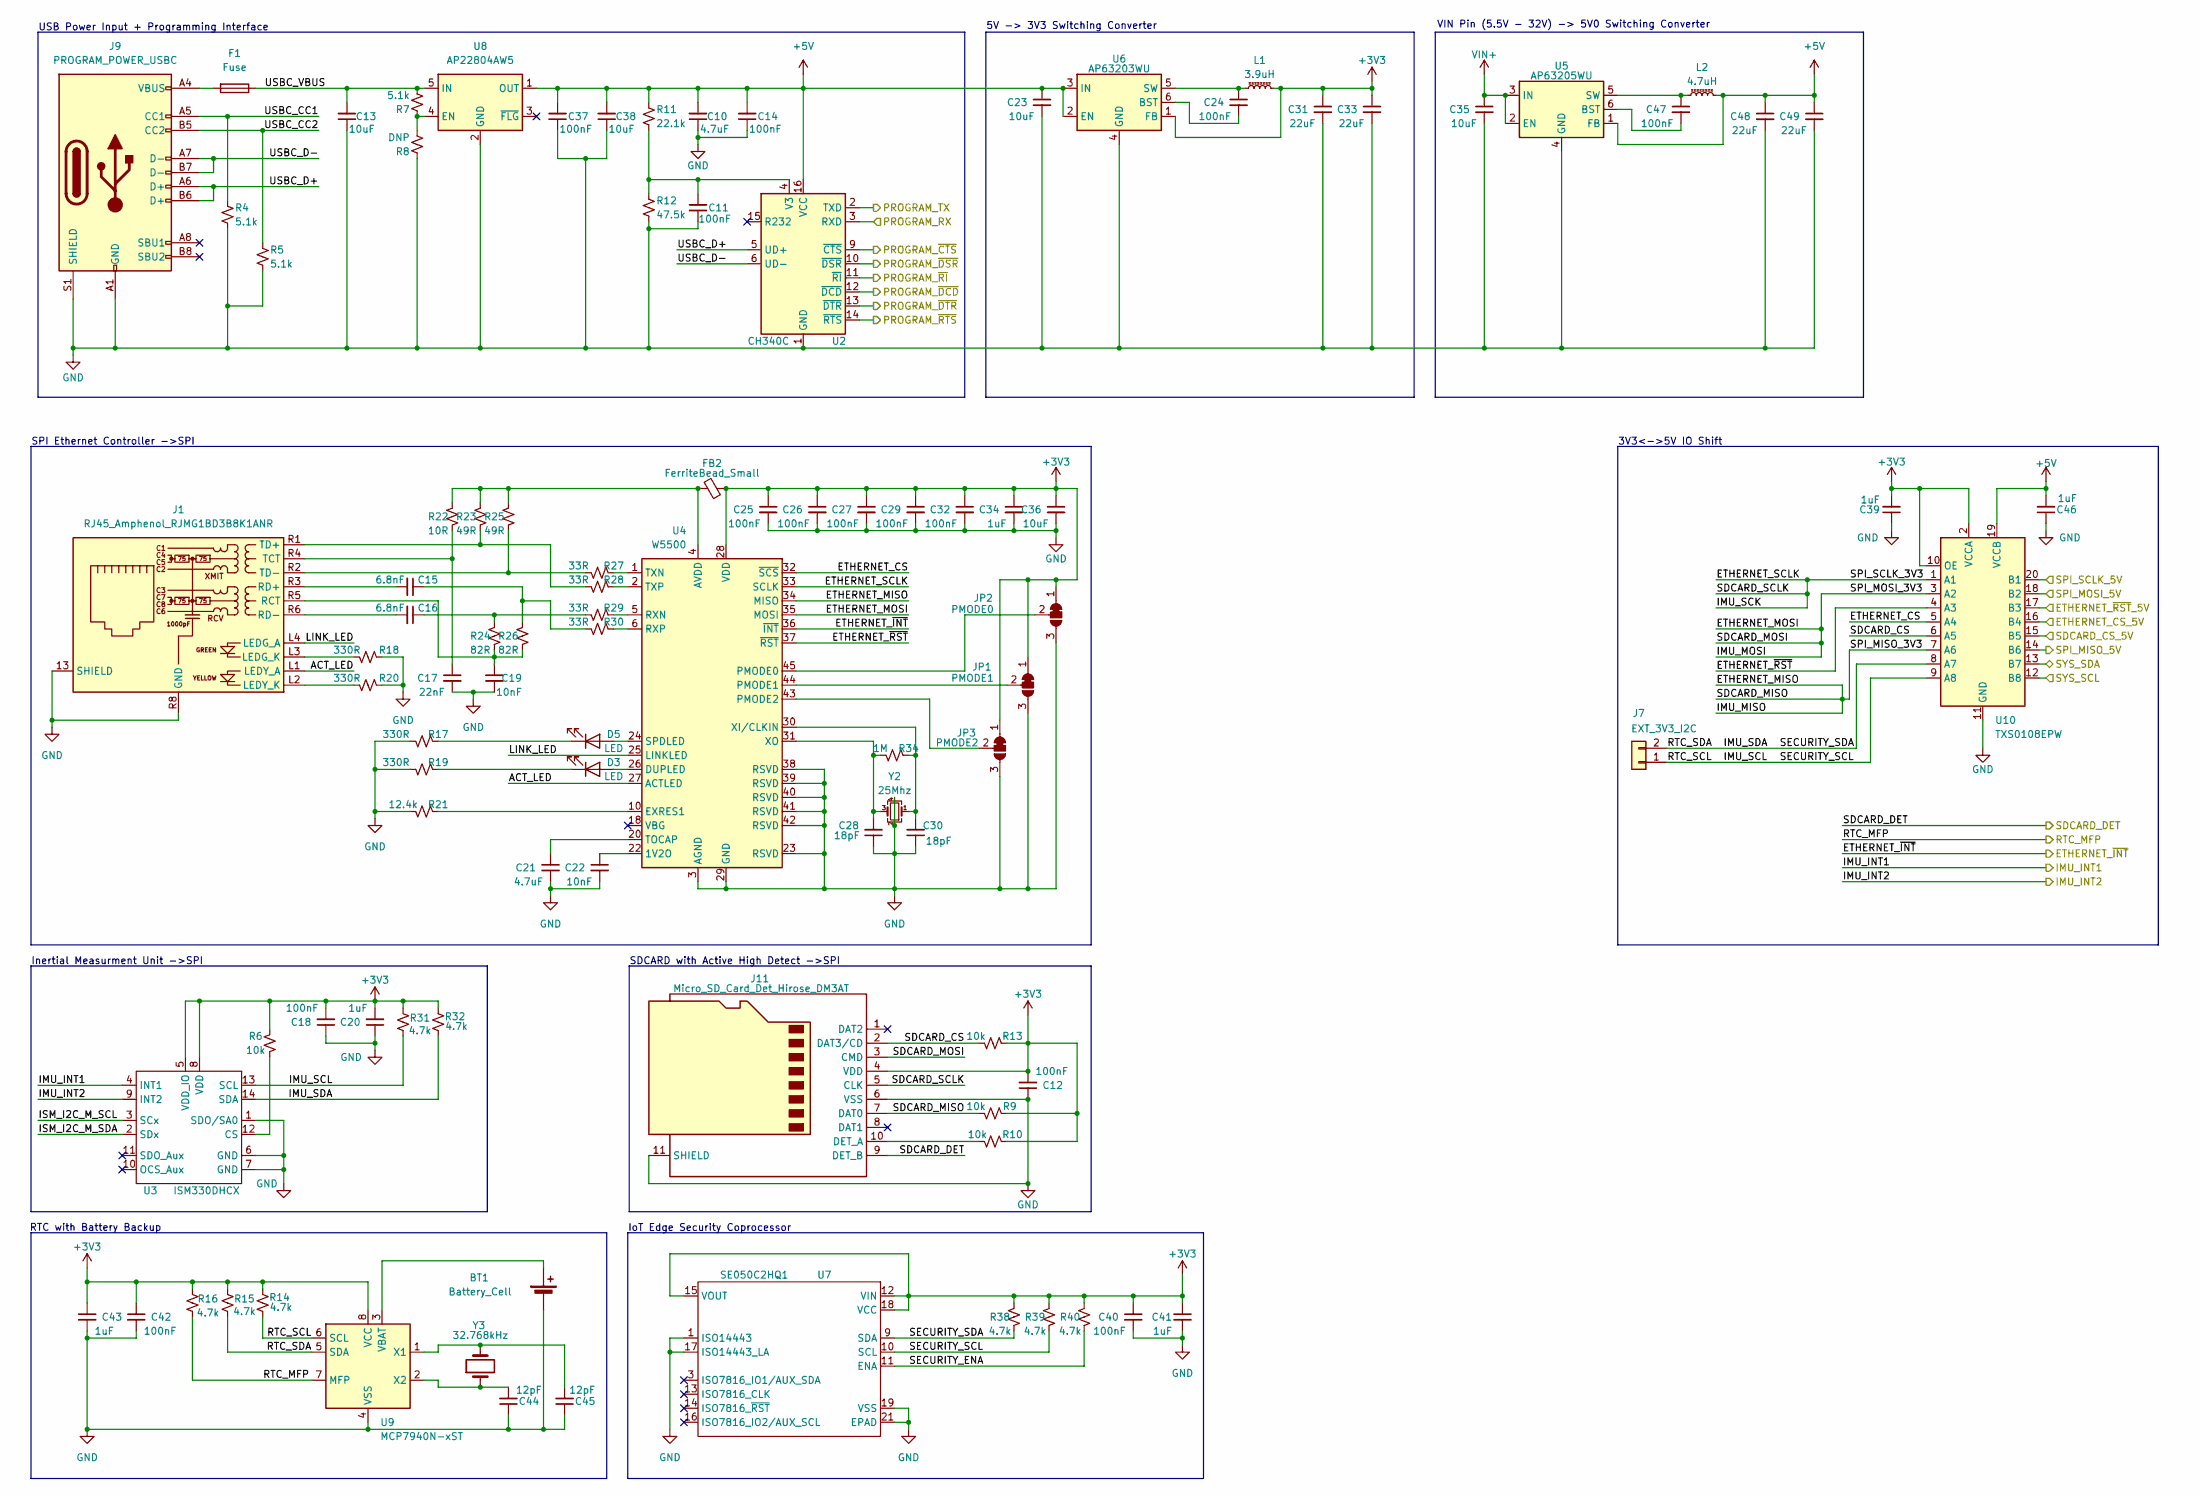
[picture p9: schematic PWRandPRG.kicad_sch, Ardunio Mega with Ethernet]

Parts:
BT1: Battery_Cell; JST_PH_B2B-PH-K_1x02_P2.00mm_Vertical
C10, C21: 4.7uF; C_0805_2012Metric_Pad1.18x1.45mm_HandSolder
C11, C12, C14, C18, C24, C25, C26, C27, C29, C32, C37, C40, C42, C47: 100nF; C_0603_1608Metric
C13, C23, C35, C36, C38: 10uF; C_0805_2012Metric_Pad1.18x1.45mm_HandSolder
C15, C16: 6.8nF; C_0603_1608Metric
C17: 22nF; C_0603_1608Metric
C19, C22: 10nF; C_0603_1608Metric
C20, C34, C39, C41, C43, C46: 1uF; C_0603_1608Metric
C28, C30: 18pF; C_0402_1005Metric_Pad0.74x0.62mm_HandSolder
C31, C33, C48, C49: 22uF; C_1210_3225Metric_Pad1.33x2.70mm_HandSolder
C44, C45: 12pF; C_0402_1005Metric_Pad0.74x0.62mm_HandSolder
D3, D5: LED; LED_0603_1608Metric
F1: Fuse; Fuse_1206_3216Metric
FB2: FerriteBead_Small; L_0603_1608Metric
J1: RJ45_Amphenol_RJMG1BD3B8K1ANR
J7: EXT_3V3_I2C; PinHeader_1x02_P2.54mm_Vertical
J9: PROGRAM_POWER_USBC; USB_C_Receptacle_HRO_TYPE-C-31-M-12
J11: Micro_SD_Card_Det_Hirose_DM3AT; microSD_HC_Hirose_DM3AT-SF-PEJM5
JP1: PMODE1; SolderJumper-3_P1.3mm_Bridged12_Pad1.0x1.5mm
JP2: PMODE0; SolderJumper-3_P1.3mm_Bridged12_Pad1.0x1.5mm
JP3: PMODE2; SolderJumper-3_P1.3mm_Bridged12_Pad1.0x1.5mm
L1: 3.9uH; L_APV_ANR6028
L2: 4.7uH; L_APV_ANR6028
R4, R5, R7: 5.1k; R_0603_1608Metric
R6, R9, R10, R13: 10k; R_0603_1608Metric
R8: DNP; R_0603_1608Metric
R11: 22.1k; R_0603_1608Metric
R12: 47.5k; R_0603_1608Metric
R14, R15, R16, R31, R32, R38, R39, R40: 4.7k; R_0603_1608Metric
R17, R18, R19, R20: 330R; R_0603_1608Metric
R21: 12.4k; R_0603_1608Metric
R22: 10R; R_0603_1608Metric
R23, R25: 49R; R_0603_1608Metric
R24, R26: 82R; R_0603_1608Metric
R27, R28, R29, R30: 33R; R_0603_1608Metric
R34: 1M; R_0603_1608Metric
U2: CH340C; SOIC-16_3.9x9.9mm_P1.27mm
U3: ISM330DHCX; LGA-14_3x2.5mm_P0.5mm_LayoutBorder3x4y
U4: W5500; LQFP-48_7x7mm_P0.5mm
U5: AP63205WU; TSOT-23-6
U6: AP63203WU; TSOT-23-6
U7: SE050C2HQ1; QFN-20-1EP_3x3mm_P0.4mm_EP1.65x1.65mm
U8: AP22804AW5; SOT-23-5
U9: MCP7940N-xST; MSOP-8_3x3mm_P0.65mm
U10: TXS0108EPW; TSSOP-20_4.4x6.5mm_P0.65mm
Y2: 25Mhz; Crystal_SMD_3225-4Pin_3.2x2.5mm
Y3: 32.768kHz; Crystal_SMD_EuroQuartz_EQ161-2Pin_3.2x1.5mm_HandSoldering

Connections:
+3V3: C12.2, C18.2, C20.2, C25.1, C26.1, C27.1, C29.1, C31.1, C32.1, C33.1, C34.1, C36.1, C39.2, C40.1, C41.1, C42.1, C43.1, FB2.1, J11.4 (VDD), JP1.1 (A), JP2.1 (A), JP3.1 (A), L1.2, R6.1, R9.1, R10.1, R13.1, R14.1, R15.1, R16.1, R31.1, R32.1, R38.1, R39.1, R40.1, U3.5 (VDD_IO), U3.8 (VDD), U4.28 (VDD), U6.1 (FB), U7.12 (VIN), U7.15 (VOUT), U7.18 (VCC), U9.8 (VCC), U10.2 (VCCA), U10.10 (OE); also elsewhere on the board
+5V: C10.2, C14.2, C23.1, C37.2, C38.2, C46.2, C48.1, C49.1, L2.2, R11.2, U2.16 (VCC), U5.1 (FB), U6.2 (EN), U6.3 (IN), U8.1 (OUT), U10.19 (VCCB); also elsewhere on the board
/ETHER_CS: U10.16 (B4); also elsewhere on the board
/ETHER_~INT: U4.36 (~INT); also elsewhere on the board
/ETHER_~RST: U10.17 (B3); also elsewhere on the board
/IMU_INT1: U3.4 (INT1); also elsewhere on the board
/IMU_INT2: U3.9 (INT2); also elsewhere on the board
/PIN_D0: U2.2 (TXD); also elsewhere on the board
/PIN_D1: U2.3 (RXD); also elsewhere on the board
/PIN_D4/CS2: U10.15 (B5); also elsewhere on the board
/PIN_D20: U10.13 (B7); also elsewhere on the board
/PIN_D21: U10.12 (B8); also elsewhere on the board
/PIN_D50: U10.14 (B6); also elsewhere on the board
/PIN_D51: U10.18 (B2); also elsewhere on the board
/PIN_D52: U10.20 (B1); also elsewhere on the board
/PWRandPRG/ACT_LED: J1.L1 (LEDY_A), U4.27 (ACTLED)
/PWRandPRG/ETHERNET_CS: U4.32 (~SCS), U10.5 (A4)
/PWRandPRG/ETHERNET_MISO: J11.7 (DAT0), R9.2, U4.34 (MISO), U10.7 (A6)
/PWRandPRG/ETHERNET_MOSI: J11.3 (CMD), U4.35 (MOSI), U10.3 (A2)
/PWRandPRG/ETHERNET_SCLK: J11.5 (CLK), U4.33 (SCLK), U10.1 (A1)
/PWRandPRG/ETHERNET_~RST: U4.37 (~RST), U10.4 (A3)
/PWRandPRG/IMU_SCL: J7.1, R14.2, R31.2, R39.2, U3.13 (SCL), U7.10 (SCL), U9.6 (SCL), U10.9 (A8)
/PWRandPRG/IMU_SDA: J7.2, R15.2, R32.2, R38.2, U3.14 (SDA), U7.9 (SDA), U9.5 (SDA), U10.8 (A7)
/PWRandPRG/ISM_I2C_M_SCL: U3.3 (SCx)
/PWRandPRG/ISM_I2C_M_SDA: U3.2 (SDx)
/PWRandPRG/LINK_LED: J1.L4 (LEDG_A), U4.25 (LINKLED)
/PWRandPRG/PROGRAM_~CTS: U2.9 (~CTS)
/PWRandPRG/PROGRAM_~DCD: U2.12 (~DCD)
/PWRandPRG/PROGRAM_~DSR: U2.10 (~DSR)
/PWRandPRG/PROGRAM_~DTR: U2.13 (~DTR); also elsewhere on the board
/PWRandPRG/PROGRAM_~RI: U2.11 (~RI)
/PWRandPRG/PROGRAM_~RTS: U2.14 (~RTS)
/PWRandPRG/SDCARD_CS: J11.2 (DAT3/CD), R13.2, U10.6 (A5)
/PWRandPRG/SECURITY_ENA: R40.2, U7.11 (ENA)
/PWRandPRG/USBC_CC1: J9.A5 (CC1), R4.2
/PWRandPRG/USBC_CC2: J9.B5 (CC2), R5.2
/PWRandPRG/USBC_D+: J9.A6 (D+), J9.B6 (D+), U2.5 (UD+)
/PWRandPRG/USBC_D-: J9.A7 (D-), J9.B7 (D-), U2.6 (UD-)
/PWRandPRG/USBC_VBUS: C13.2, F1.1, R7.1, U8.5 (IN)
/RTC_MFP: R16.2, U9.7 (MFP); also elsewhere on the board
/SD_DET: J11.9 (DET_B); also elsewhere on the board
GND: BT1.2 (-), C10.1, C11.1, C12.1, C13.1, C14.1, C17.2, C18.1, C19.2, C20.1, C21.2, C22.2, C23.2, C25.2, C26.2, C27.2, C28.1, C29.2, C30.1, C31.2, C32.2, C33.2, C34.2, C35.2, C36.2, C37.1, C38.1, C39.1, C40.2, C41.2, C42.2, C43.2, C44.1, C45.1, C46.1, C48.2, C49.2, J1.13 (SHIELD), J1.R8 (GND), J9.A1 (GND), J9.A12 (GND), J9.B1 (GND), J9.B12 (GND), J9.S1 (SHIELD), J11.6 (VSS), J11.11 (SHIELD), JP1.3 (B), JP2.3 (B), JP3.3 (B), R4.1, R5.1, R8.2, R12.1, R17.2, R18.1, R19.2, R20.1, R21.2, U2.1 (GND), U3.1 (SDO/SA0), U3.6 (GND), U3.7 (GND), U4.3 (AGND), U4.9 (AGND), U4.14 (AGND), U4.16 (AGND), U4.19 (AGND), U4.23 (RSVD), U4.29 (GND), U4.38 (RSVD), U4.39 (RSVD), U4.40 (RSVD), U4.41 (RSVD), U4.42 (RSVD), U4.48 (AGND), U5.4 (GND), U6.4 (GND), U7.1 (ISO14443), U7.17 (ISO14443_LA), U7.19 (VSS), U7.21 (EPAD), U8.2 (GND), U9.4 (VSS), U10.11 (GND), Y2.2, Y2.4; also elsewhere on the board
unnamed: BT1.1 (+), U9.3 (VBAT)
unnamed: C15.1, R26.1, R30.2
unnamed: C16.1, R24.1, R29.2
unnamed: D3.2 (A), U4.26 (DUPLED)
unnamed: D3.1 (K), R19.1
unnamed: D5.2 (A), U4.24 (SPDLED)
unnamed: D5.1 (K), R17.1
unnamed: F1.2, J9.A4 (VBUS), J9.A9 (VBUS), J9.B4 (VBUS), J9.B9 (VBUS)
unnamed: FB2.2, R22.1, R23.1, R25.1, U4.4 (AVDD), U4.8 (AVDD), U4.11 (AVDD), U4.15 (AVDD), U4.17 (AVDD), U4.21 (AVDD)
unnamed: J1.L3 (LEDG_K), R18.2
unnamed: J1.L2 (LEDY_K), R20.2
unnamed: C19.1, J1.R5 (RCT), R24.2, R26.2
unnamed: C15.2, J1.R3 (RD+)
unnamed: C16.2, J1.R6 (RD-)
unnamed: C17.1, J1.R4 (TCT), R22.2
unnamed: J1.R1 (TD+), R23.2, R28.2
unnamed: J1.R2 (TD-), R25.2, R27.2
unnamed: J11.10 (DET_A), R10.2
unnamed: JP1.2 (C), U4.44 (PMODE1)
unnamed: JP2.2 (C), U4.45 (PMODE0)
unnamed: JP3.2 (C), U4.43 (PMODE2)
unnamed: C11.2, R11.1, R12.2, U2.4 (V3)
unnamed: R6.2, U3.12 (CS)
unnamed: C22.1, U4.22 (1V2O)
unnamed: R21.1, U4.10 (EXRES1)
unnamed: R29.1, U4.5 (RXN)
unnamed: R30.1, U4.6 (RXP)
unnamed: C21.1, U4.20 (TOCAP)
unnamed: R27.1, U4.1 (TXN)
unnamed: R28.1, U4.2 (TXP)
unnamed: C30.2, R34.1, U4.30 (XI/CLKIN), Y2.1
unnamed: C28.2, R34.2, U4.31 (XO), Y2.3
unnamed: C47.2, U5.6 (BST)
unnamed: C47.1, L2.1, U5.5 (SW)
unnamed: C24.2, U6.6 (BST)
unnamed: C24.1, L1.1, U6.5 (SW)
unnamed: R7.2, R8.1, U8.4 (EN)
unnamed: C45.2, U9.1 (X1), Y3.2
unnamed: C44.2, U9.2 (X2), Y3.1
VIN+: C35.1, U5.2 (EN), U5.3 (IN); also elsewhere on the board

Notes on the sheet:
SPI Ethernet Controller ->SPI
3V3<->5V IO Shift
USB Power Input + Programming Interface
IoT Edge Security Coprocessor
VIN Pin (5.5V - 32V) -> 5V0 Switching Converter
SDCARD with Active High Detect ->SPI
5V -> 3V3 Switching Converter
RTC with Battery Backup
Inertial Measurment Unit ->SPI

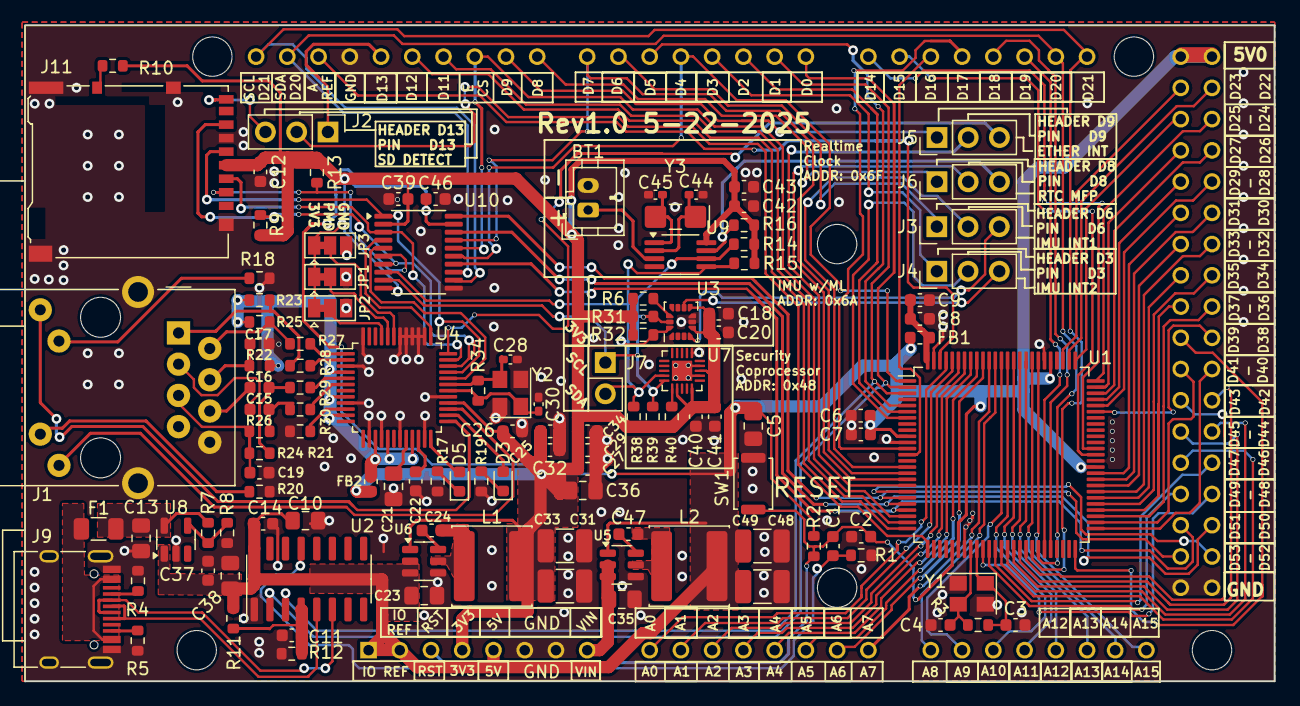
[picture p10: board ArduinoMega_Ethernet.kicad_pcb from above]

Board: 2 copper layers, 101.6 x 53.3 mm, 120 parts (0 on the bottom side), 145 nets.

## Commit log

2025-05-17 remove old schematic
2025-05-18 add usb protection, fix ioref
    [ArduinoMega_Ethernet.kicad_pcb, ArduinoMega_Ethernet.kicad_sch, PWRandPRG.kicad_sch]
2025-05-18 Fix IMU I2C, add SD Detect, Fix IoT CoPro Power
    [ArduinoMega_Ethernet-B_Cu.gbr, ArduinoMega_Ethernet-B_Mask.gbr, ArduinoMega_Ethernet-B_Paste.gbr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]
2025-05-18 update with imu and copro changes
2025-05-18 schematic with toggle io and rtc
2025-05-19 configurable io jumpers
    configurable io jumpers
    [ArduinoMega_Ethernet-B_Cu.gbr, ArduinoMega_Ethernet-B_Mask.gbr, ArduinoMega_Ethernet-B_Paste.gbr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]
2025-05-19 update pos
    [ArduinoMega_Ethernet-top-pos.csv]
2025-05-20 I2C and Silkscreen revision
    [ArduinoMega_Ethernet-B_Cu.gbr, ArduinoMega_Ethernet-B_Mask.gbr, ArduinoMega_Ethernet-B_Paste.gbr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]
2025-05-20 level shift i2c note
2025-05-21 update level shifter, configurable pmode
    [ArduinoMega_Ethernet-B_Cu.gbr, ArduinoMega_Ethernet-B_Mask.gbr, ArduinoMega_Ethernet-B_Paste.gbr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]
2025-05-21 update capacitor footprints
    [ArduinoMegaEthernetBOM.ods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]
2025-05-21 Add files via upload
    fix undersized capacitors
    [ArduinoMega_Ethernet.kicad_pcb, ArduinoMega_Ethernet.kicad_sch, PWRandPRG.kicad_sch]
2025-05-22 fix VIN pin
    [ArduinoMega_Ethernet-B_Cu.gbr, ArduinoMega_Ethernet-B_Mask.gbr, ArduinoMega_Ethernet-B_Paste.gbr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]
2025-05-23 finished BOM and component sizing
    [ArduinoMegaEthernetBOM - BOM_REV1.0.csv, ArduinoMegaEthernetBOM.ods, ArduinoMegaEthernetBOM.xlsx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]
2025-05-23 swap sd card mosi miso
    [ArduinoMega_Ethernet-B_Cu.gbr, ArduinoMega_Ethernet-B_Mask.gbr, ArduinoMega_Ethernet-B_Paste.gbr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]
